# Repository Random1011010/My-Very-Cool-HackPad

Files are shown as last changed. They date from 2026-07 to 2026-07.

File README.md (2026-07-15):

# My Very Cool HackPad

A 6-key macropad with a rotary encoder (push-button) and a 128x32 OLED display, built around the Seeed Studio XIAO RP2040. The OLED runs an idle-animated "Luna" sprite that cycles through sit, walk, run, sleep, and work.

Screenshot 2026-07-14 at 11 34 16 PM

## About me

I'm a Grade 10 (going into Grade 11) student, I am interested in aerospace, but I wanted to get real hands-on experience with hardware and PCB design before jumping into anything bigger. This was my first full custom PCB build, so a lot of this project was just learning by doing.

## Inspiration & Challenges

I wanted something I'd actually use, not just a demo board but rather, media controls, screen brightness, and a few shortcuts I use constantly (Spotlight, screenshot, undo/redo). The OLED also mattered to me too, I didn't want it just showing static text, so it runs a small animated character instead.

Most of the challenges were on the PCB and case side, since this was my first time doing either seriously. In KiCad, I had to fix a missing net label on one of the matrix columns, and ran into alignment issues while placing components that took a while to track down. Getting the rotary encoder's footprint right was its own thing.

The case went through a full rebuild. I first modeled it with not a clue how to I would get the keys to line up with the PCB, then rebuilt it in Fusion 360, sketch by sketch, to match Hack Club's submission format, while keeping the board dimensions (84x59.5mm), switch spacing, and heatset insert placement consistent with the original.

On the firmware side, I wrote the QMK code for the matrix, the encoder (volume normally, brightness when you hold the encoder's button), and the OLED animation, I adapted an open-source Luna sprite animation to loop continuously instead of reacting to typing, since I wanted it to feel more like a little idle character than a status display.
(Hopefully it works)

## Features

- 6-key matrix (2 rows x 3 columns)
- Rotary encoder with push-button:
  - Rotate: volume up/down (default)
  - Hold + rotate: screen brightness up/down
  - Short tap: play/pause
- 128x32 I2C OLED with an idle-animated Luna sprite
- QMK firmware, fully open source

## Bill of Materials (BOM)

| Part | Qty | Unit Cost | Total | Notes |
|---|---|---|---|---|
| Seeed Studio XIAO RP2040 | 1 | $5.00 | $5.00 | Main MCU |
| Cherry MX-style switches | 6 | $0.35 | $2.10 | |
| Keycaps | 6 | $0.30 | $1.80 | |
| Rotary encoder (EC11) with push-button | 1 | $0.90 | $0.90 | |
| 128x32 I2C OLED display (SSD1306) | 1 | $5.90 | $5.90 | |
| Custom PCB | 1 | ~$5.00 | $5.00 | 2-layer, JLCPCB/similar, price for small qty |
| 3D printed case | 1 | ~$3.00 | $3.00 | Filament cost estimate |
| M3 heatset inserts | 6 | $0.10 | $0.60 | |
| Diodes | 6 | $0.05 | $0.30 | 1N4148, one per switch |
| **Total** | | | **~$24.60** | |

## Pinout

| Function | Pin |
|---|---|
| Matrix rows | GP26, GP27 |
| Matrix cols | GP29, GP0, GP3 |
| Encoder A/B | GP2, GP1 |
| Encoder switch | GP28 |
| OLED SDA | GP6 |
| OLED SCL | GP7 |

## Photos

**Exploded View**
Screenshot 2026-07-15 at 12 25 32 AM

**Schematic:**

Screenshot 2026-07-14 at 11 25 23 PM

**PCB:**

Screenshot 2026-07-14 at 11 26 05 PM

**Case:**



**Firmware**
Written in QMK. Full source is in the `firmware/` folder — see [`firmware/myverycoolpad/readme.md`](firmware/myverycoolpad/readme.md) for build/flash instructions.

**Status**
Parts haven't arrived yet, so the physical build and OLED orientation are untested. Firmware compiles cleanly with `qmk compile -kb myverycoolpad -km default`.

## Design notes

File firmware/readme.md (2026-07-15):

# myverycoolpad

*A 6-key macropad with a rotary encoder (push-button), and an OLED display, built around the Seeed Studio XIAO RP2040.*

* Keyboard Maintainer: [Adhyan Mahindru](https://github.com/Random1011010)
* Hardware Supported: Seeed Studio XIAO RP2040
* Hardware Availability: Custom PCB, designed in KiCad; case designed in Fusion 360 (files in project repo)

## Features

- **6-key matrix** (2 rows x 3 columns) with media/shortcut keycodes (previous/next track, Spotlight, Mission Control, screenshot, undo/redo)
- **Rotary encoder** with push-button switch:
  - Rotate: volume up/down (default mode)
  - Hold the encoder switch to toggle into brightness mode, then rotate for screen brightness up/down
  - Short tap of the encoder switch: play/pause
- **128x32 I2C OLED display** running an idle-animated "Luna" sprite (sit/walk/run/bark/sneak cycle), adapted from [filterpaper/qmk_oled_animations](https://github.com/filterpaper/qmk_oled_animations)

## Pinout

| Function | Pin  |
|---|---|
| Matrix rows | GP26, GP27 |
| Matrix cols | GP29, GP0, GP3 |
| Encoder A/B | GP2, GP1 |
| Encoder switch| GP28 |
| OLED SDA | GP6 |
| OLED SCL | GP7 |

## Build/Flash

    qmk compile -kb myverycoolpad -km default

Put the XIAO RP2040 into bootloader mode (double-tap reset), then drag the resulting `.uf2` file onto the `RPI-RP2` drive that appears.

## Notes

- OLED rotation is currently set to `OLED_ROTATION_270` in `oled_luna.c`. This hasn't been verified on physical hardware yet — if the animation appears rotated once assembled, try `OLED_ROTATION_0`, `90`, or `180` instead.

## Bootloader

Enter the bootloader in 3 ways:

* **Bootmagic reset**: Hold down the key at (0,0) in the matrix and plug in the keyboard
* **Physical reset button**: Double-tap the reset button on the XIAO RP2040
* **Keycode in layout**: Press the key mapped to `QK_BOOT` if it is available

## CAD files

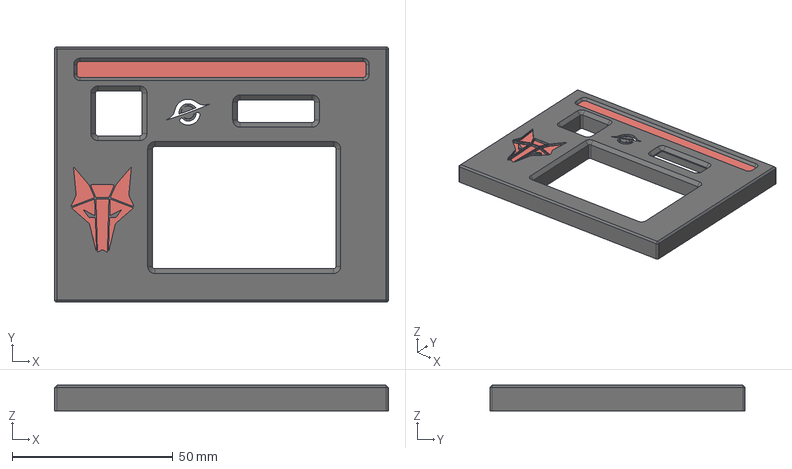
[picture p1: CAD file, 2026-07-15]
production/Top Plate.step
104.0 x 79.5 x 8.00 mm

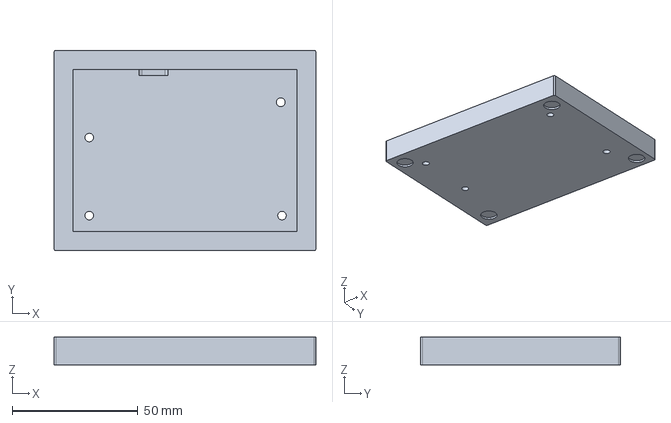
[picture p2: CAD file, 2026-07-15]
production/Bottom Plate.step
104.0 x 79.5 x 11.0 mm

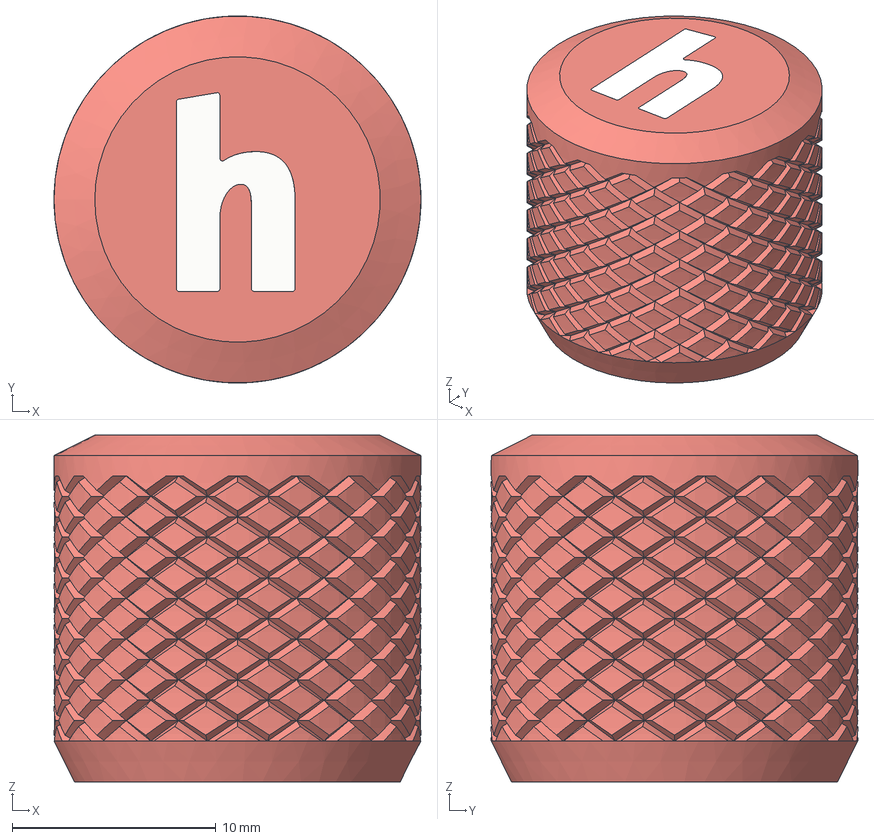
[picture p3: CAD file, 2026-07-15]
production/HackClubKnob.step
18.0 x 18.0 x 17.0 mm

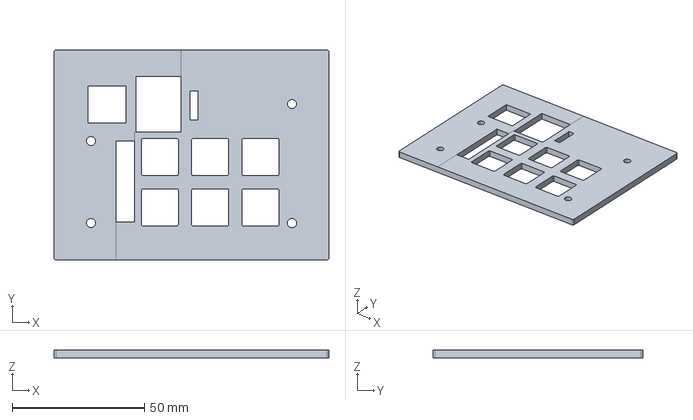
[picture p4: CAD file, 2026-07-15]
production/Mid plate.step
104.0 x 79.5 x 3.01 mm

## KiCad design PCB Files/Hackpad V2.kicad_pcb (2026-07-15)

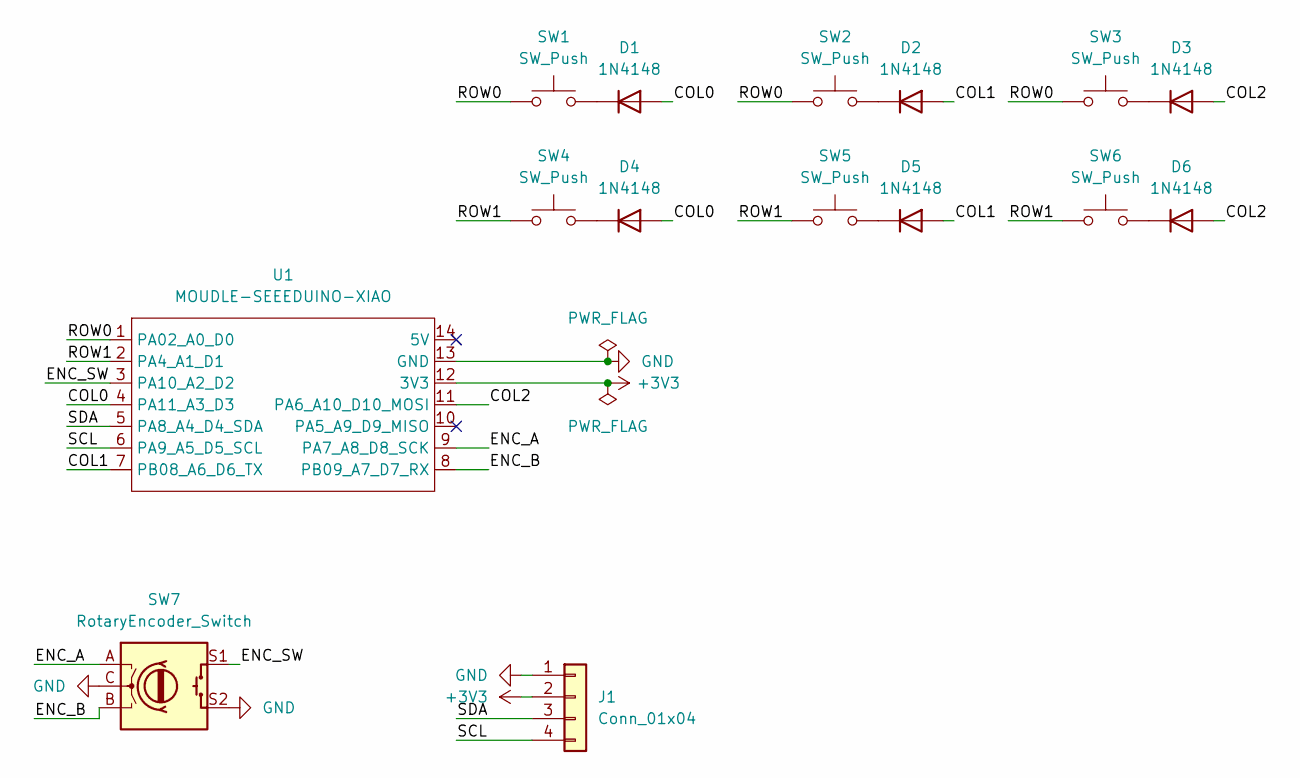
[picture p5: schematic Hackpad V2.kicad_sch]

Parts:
D1, D2, D3, D4, D5, D6: 1N4148; D_DO-35_SOD27_P7.62mm_Horizontal
J1: Conn_01x04; PinHeader_1x04_P2.54mm_Vertical
SW1, SW2, SW3, SW4, SW5, SW6: SW_Push; SW_Cherry_MX_1.00u_PCB
SW7: RotaryEncoder_Switch; RotaryEncoder_Alps_EC11E-Switch_Vertical_H20mm
U1: MOUDLE-SEEEDUINO-XIAO; XIAO-Generic-Hybrid-14P-2.54-21X17.8MM

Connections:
+3V3: J1.2, U1.12 (3V3)
/COL0: D1.2 (A), D4.2 (A), U1.4 (PA11_A3_D3)
/COL1: D2.2 (A), D5.2 (A), U1.7 (PB08_A6_D6_TX)
/COL2: D3.2 (A), D6.2 (A), U1.11 (PA6_A10_D10_MOSI)
/ENC_A: SW7.A, U1.9 (PA7_A8_D8_SCK)
/ENC_B: SW7.B, U1.8 (PB09_A7_D7_RX)
/ENC_SW: SW7.S1, U1.3 (PA10_A2_D2)
/ROW0: SW1.1, SW2.1, SW3.1, U1.1 (PA02_A0_D0)
/ROW1: SW4.1, SW5.1, SW6.1, U1.2 (PA4_A1_D1)
/SCL: J1.4, U1.6 (PA9_A5_D5_SCL)
/SDA: J1.3, U1.5 (PA8_A4_D4_SDA)
GND: J1.1, SW7.C, SW7.S2, U1.13 (GND)
unnamed: D1.1 (K), SW1.2
unnamed: D2.1 (K), SW2.2
unnamed: D3.1 (K), SW3.2
unnamed: D4.1 (K), SW4.2
unnamed: D5.1 (K), SW5.2
unnamed: D6.1 (K), SW6.2

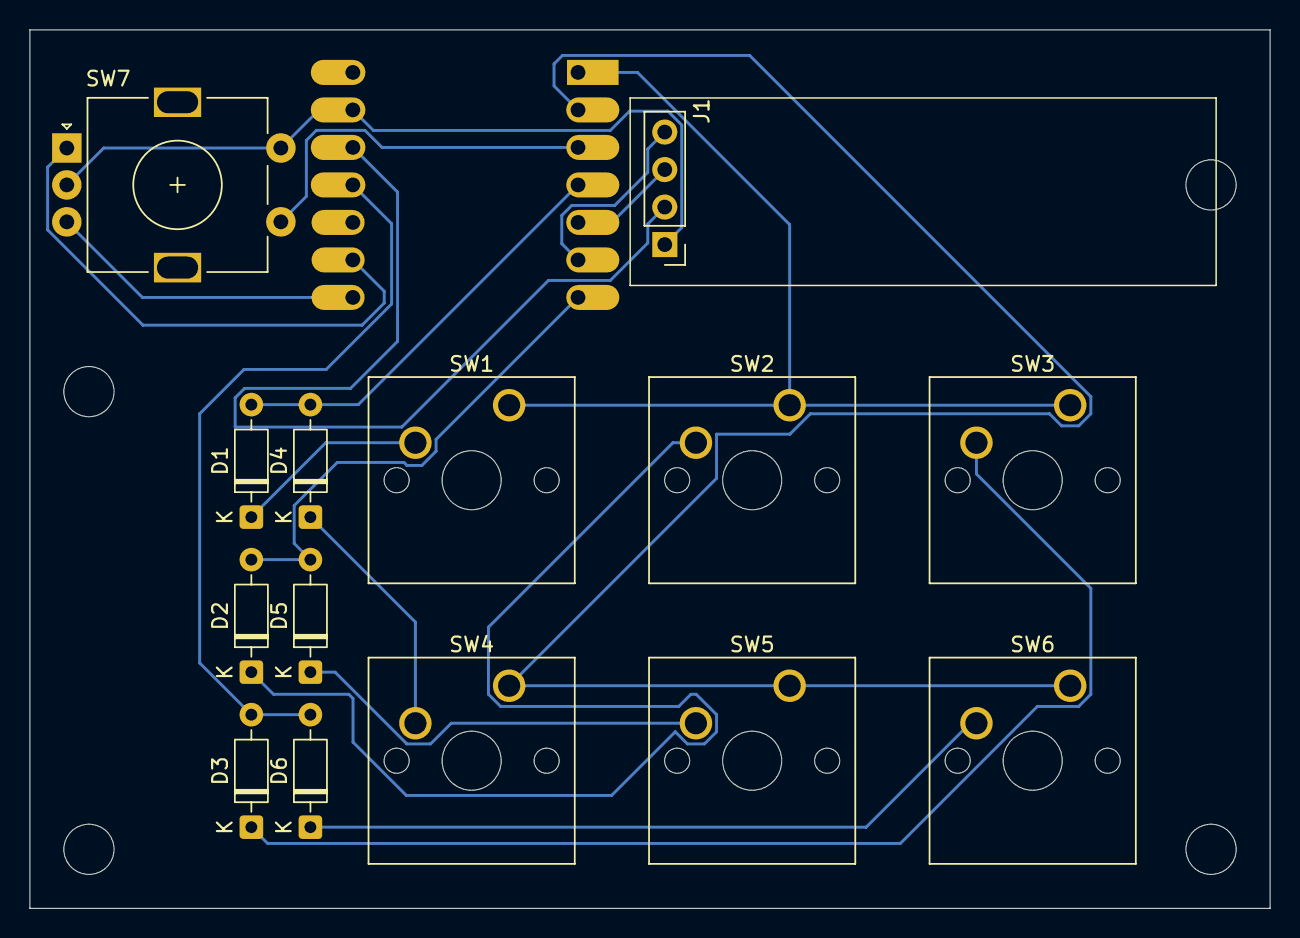
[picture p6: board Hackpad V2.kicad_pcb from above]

Board: 2 copper layers, 84.0 x 59.5 mm, 15 parts (1 on the bottom side), 18 nets.

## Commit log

2026-07-01 Create PCB files
2026-07-01 Create Case Files
2026-07-15 Rename Case Files to Case
2026-07-15 Added PCB Files
    [Hackpad V2.kicad_pcb, Hackpad V2.kicad_sch]
2026-07-15 Revise README with detailed project information
    Expanded project description, added features, BOM, pinout, and photos sections.
2026-07-15 Added Case models into production
    [Bottom Plate.step, HackClubKnob.step, Mid plate.step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]
2026-07-15 Enhance BOM with unit costs and total calculation
    Updated the Bill of Materials (BOM) section to include unit costs and total cost.
